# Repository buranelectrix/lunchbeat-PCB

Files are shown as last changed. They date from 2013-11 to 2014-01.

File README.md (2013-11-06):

lunchbeat - 1bit groovebox - PCB version
========================================
by Jan Cumpelik (jan@buranelectrix.com)

Hi. Here it is, Lunchbeat made it from breadboard to printed circuit board :)

"lunchbeat-PCB-firmware" contains source C code for Atmega328p 

"lunchbeat-PCB-hardware" contains resources for building Lunchbeat. Schematics, printed circuit board design. And whole Kicad project including library with used parts :)  Kicad is nice free software, use it :)

Feel free to use these files (read license first).

If you use this to create something cool, please let me know! 
If you find any flaw, please let me know!

Thank you, Jan.

The firmware is released under a GPL3.0 license.
The PCB layout and schematics are released under cc-by-sa 3.0 license. 

more info: www.buranelectrix.com

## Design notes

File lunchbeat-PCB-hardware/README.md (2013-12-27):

Lunchbeat hardware
==================

here you can find:

- whole KiCad project with latest Lunchbeat hardware revision

- partlist

- schematics

Part list now included in ODS file (OpenDocument Spreadsheet).

Jan

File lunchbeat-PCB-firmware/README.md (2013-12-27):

Lunchbeat version history file
==============================

Lunchbeat PCB 1.3
-----------------
* setup function renamed (for Arduino users)
+ SYNC IN now on ISP MISO pin
+ TRIG OUT goes always

Lunchbeat PCB 1.2
-----------------
+ selectable EXT or INT clock
+ clock division
+ setup mode

Lunchbeat PCB 1.1
-----------------
* several connections changed to better fit on PCB :)

Lunchbeat breadboard 1.0
------------------------
+ original Lunchbeat

======================
buranelectrix.com 2013
======================

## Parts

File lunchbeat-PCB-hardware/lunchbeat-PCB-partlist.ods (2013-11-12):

LUNCHBEAT PART LIST |  |  | buranelectrix.com
lunchbeat part | pcs | part name | manufacturer
mcu | 1 | ATMEGA328P-PU | ATMEL
mcu socket | 1 | ICVT-28P-W | NINIGI
crystal 16MHz | 1 | 16.00M-HC49-S | YIC
22pF capacitor | 2 | C315C220J2G5TA | KEMET
74595 shift register | 1 | 74HC595 | ST MICROELECTRONICS
shift register socket | 1 | ICVT-16P | NINIGI
red LED | 2 | 3mm LED | LUCKY LIGHT
blue LED | 8 | 3mm LED | LUCKY LIGHT
led resistors – depends on your LEDs | 10 | 1/4W3.3K | ROYAL OHM
pots | 6 | RK09K1130A8G | ALPS
buttons | 6 | TACT-65N-F | NINIGI
reset button | 1 | TACT-65R-F | NINIGI
reset resistor | 1 | 1/4W10K | ROYAL OHM
r2r resistors | 8 | 1/4W100K | ROYAL OHM
opamp | 1 | LM358AN | ST MICROELECTRONICS
opamp socket | 1 | ICVT-8P | NINIGI
output cap | 1 | KM10/63 | SAMXON
output protection r | 1 | 1/4W100R | ROYAL OHM
jack connector | 2 | FC68131 | CLIFF
battery holder | 1 | KEYS1295 | KEYSTONE
power switch | 1 | ZL201-10G | CONNFLY
5v stabiliser | 1 | L78L05ABZ | ST MICROELECTRONICS
330nF cap | 1 | C320C334K1R5TA | KEMET
220uF cap | 1 | KM220/25 | SAMXON
100nF coupling caps | 4 | C320C104K5R5TA | KEMET
ISP | 1 | DS1021-1*10SF11 | CONNFLY

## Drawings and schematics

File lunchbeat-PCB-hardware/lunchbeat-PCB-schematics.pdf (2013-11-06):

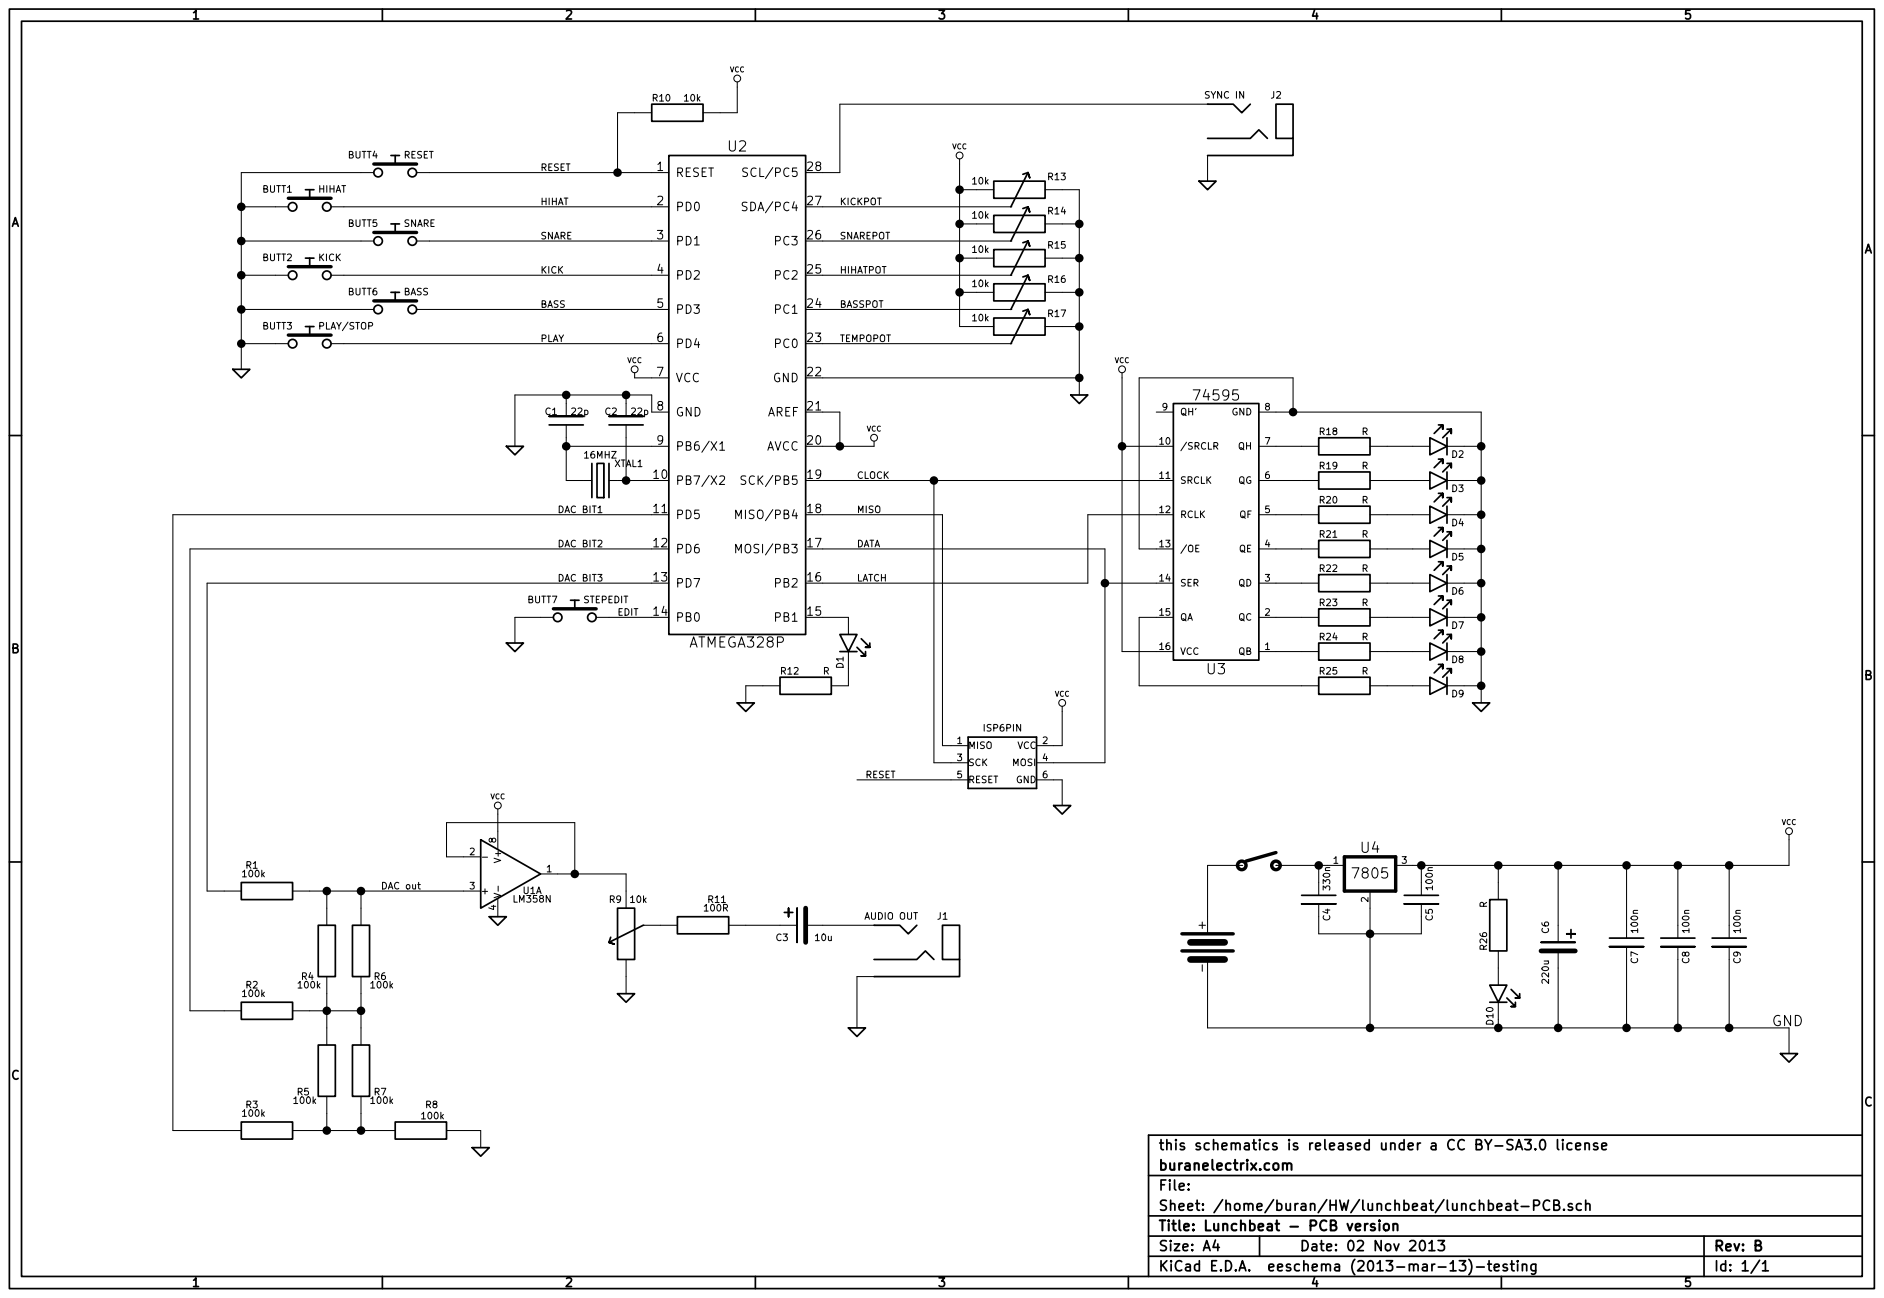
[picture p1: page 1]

DATA RESET HIHAT SNARE

TEMPOPOT BASSPOT HIHATPOT SNAREPOT KICKPOT

- +C6 220uC7 100n C8 100n D10 R26 R MISO 1 VCC 2 SCK 3 MOSI 4 RESET 5 GND 6

this schematics is released under a CC BY-SA3.0 license buranelectrix.com

Sheet: /home/buran/HW/lunchbeat/lunchbeat-PCB.sch File: Title: Lunchbeat - PCB version

KiCad E.D.A. eeschema (2013-mar-13)-testing Date: 02 Nov 2013

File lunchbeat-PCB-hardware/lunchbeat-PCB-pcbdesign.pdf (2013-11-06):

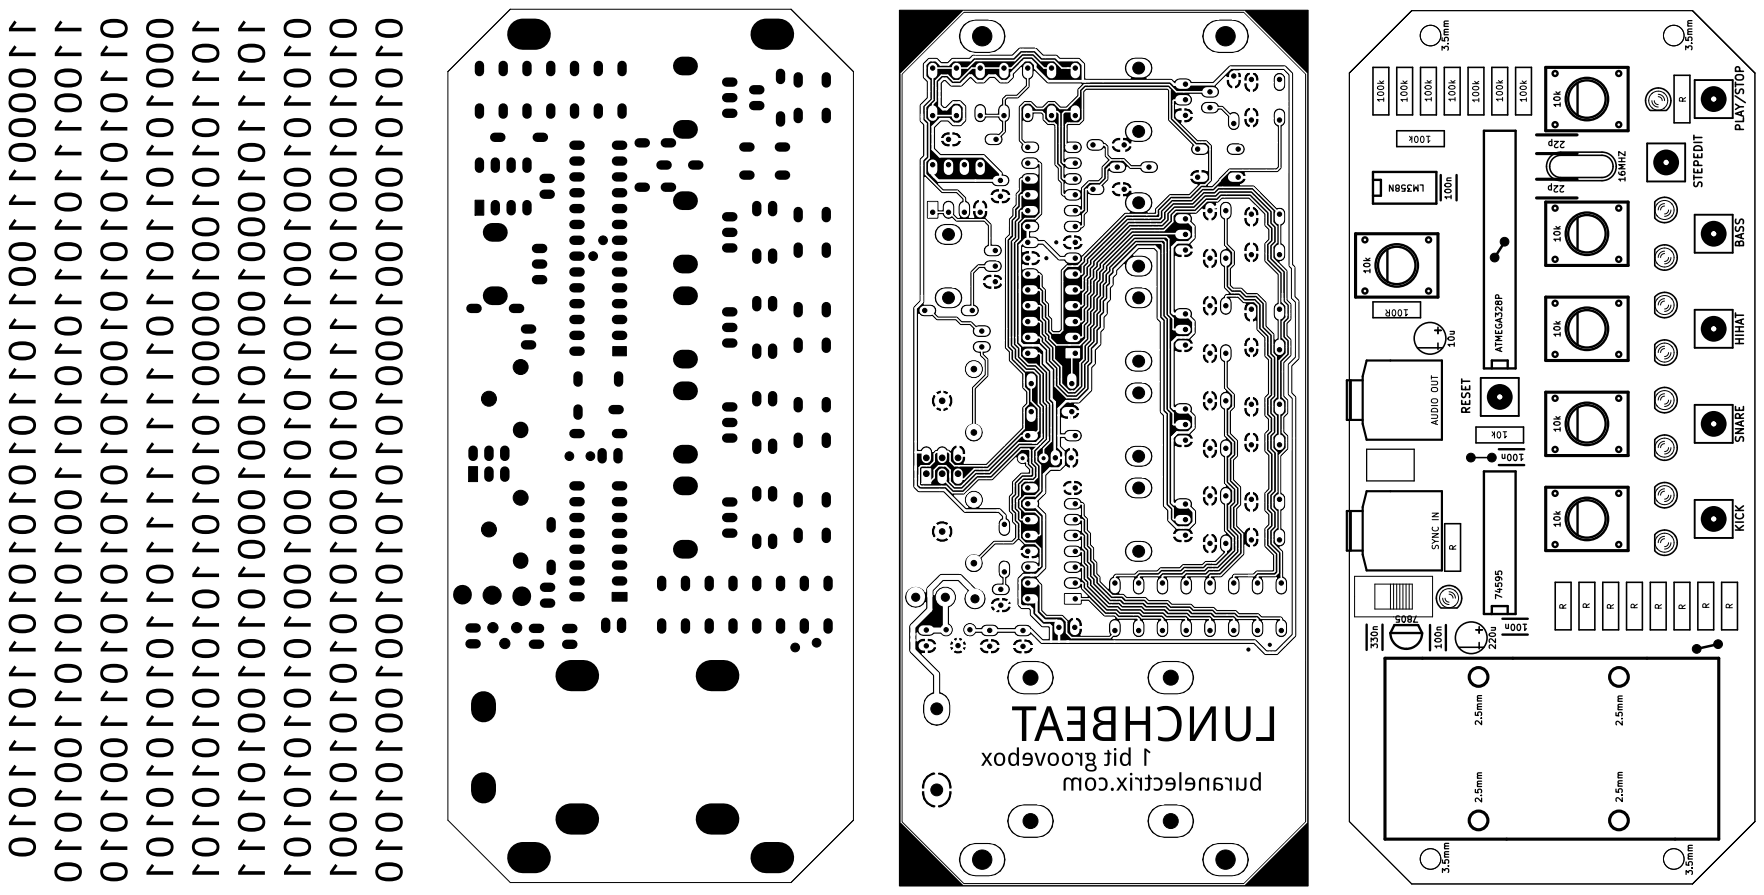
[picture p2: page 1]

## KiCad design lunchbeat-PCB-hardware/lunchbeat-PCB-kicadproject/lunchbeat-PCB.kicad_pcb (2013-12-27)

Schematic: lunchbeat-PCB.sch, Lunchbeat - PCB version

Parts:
6PIN1: ISP6PIN
B1: BATTERY
BUTT1: HIHAT
BUTT2: KICK
BUTT3: PLAY/STOP
BUTT4: RESET
BUTT5: SNARE
BUTT6: BASS
BUTT7: STEPEDIT
C1, C2: 22p
C3: 10u
C4: 330n
C5, C7, C8, C9: 100n
C6: 220u
D1, D2, D3, D4, D5, D6, D7, D8, D9, D10: LED
J1: AUDIO OUT
J2: SYNC IN
R1, R2, R3, R4, R5, R6, R7, R8: 100k
R9, R10, R13, R14, R15, R16, R17: 10k
R11: 100R
R12, R18, R19, R20, R21, R22, R23, R24, R25, R26: R
SW1: SW-PW
U1: LM358N
U2: ATMEGA328P
U3: 74595
U4: 7805
XTAL1: 16MHZ

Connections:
/BASS: BUTT6.2, U2.5 (PD3)
/BASSPOT: R16.2, U2.24 (PC1)
/CLOCK: 6PIN1.3 (SCK), U2.19 (SCK/PB5), U3.11 (SRCLK)
/DAC BIT1: R3.2, U2.11 (PD5)
/DAC BIT2: R2.2, U2.12 (PD6)
/DAC BIT3: R1.2, U2.13 (PD7)
/DAC out: R1.1, R4.2, R6.2, U1.3 (+)
/DATA: 6PIN1.4 (MOSI), U2.17 (MOSI/PB3), U3.14 (SER)
/EDIT: BUTT7.2, U2.14 (PB0)
/HIHAT: BUTT1.2, U2.2 (PD0)
/HIHATPOT: R15.2, U2.25 (PC2)
/KICK: BUTT2.2, U2.4 (PD2)
/KICKPOT: R13.2, U2.27 (SDA/PC4)
/LATCH: U2.16 (PB2), U3.12 (RCLK)
/MISO: 6PIN1.1 (MISO), U2.18 (MISO/PB4)
/PLAY: BUTT3.2, U2.6 (PD4)
/RESET: 6PIN1.5 (RESET), BUTT4.2, R10.1, U2.1 (RESET)
/SNARE: BUTT5.2, U2.3 (PD1)
/SNAREPOT: R14.2, U2.26 (PC3)
/TEMPOPOT: R17.2, U2.23 (PC0)
/batvcc: B1.2 (+), SW1.1
unnamed: D10.1, R26.1
unnamed: R9.3, U1.1, U1.2 (-)
unnamed: R9.2, R11.1
unnamed: C3.1, R11.2
unnamed: C4.2, SW1.2, U4.1 (IN)
unnamed: D1.2, R12.2
unnamed: D1.1, U2.15 (PB1)
unnamed: C2.2, U2.10 (PB7/X2), XTAL1.1
unnamed: J2.1, U2.28 (SCL/PC5)
unnamed: R2.1, R4.1, R5.2, R6.1, R7.2
unnamed: C1.2, U2.9 (PB6/X1), XTAL1.2
unnamed: C3.2, J1.1
unnamed: D6.1, R22.2
unnamed: D5.1, R21.2
unnamed: D4.1, R20.2
unnamed: D3.1, R19.2
unnamed: D2.1, R18.2
unnamed: R18.1, U3.7 (QH)
unnamed: R19.1, U3.6 (QG)
unnamed: R20.1, U3.5 (QF)
unnamed: R21.1, U3.4 (QE)
unnamed: R22.1, U3.3 (QD)
unnamed: R25.1, U3.15 (QA)
unnamed: D9.1, R25.2
unnamed: R24.1, U3.1 (QB)
unnamed: D8.1, R24.2
unnamed: R23.1, U3.2 (QC)
unnamed: D7.1, R23.2
unnamed: R3.1, R5.1, R7.1, R8.1
VCC: 6PIN1.2 (VCC), C5.2, C6.1, C7.2, C8.2, C9.2, R10.2, R13.3, R14.3, R15.3, R16.3, R17.3, R26.2, U1.8 (V+), U2.7 (VCC), U2.20 (AVCC), U2.21 (AREF), U3.10 (/SRCLR), U3.16 (VCC), U4.3 (OUT)
~: 6PIN1.6 (GND), B1.1 (-), BUTT1.1, BUTT2.1, BUTT3.1, BUTT4.1, BUTT5.1, BUTT6.1, BUTT7.1, C1.1, C2.1, C4.1, C5.1, C6.2, C7.1, C8.1, C9.1, D2.2, D3.2, D4.2, D5.2, D6.2, D7.2, D8.2, D9.2, D10.2, J1.3, J2.3, R8.2, R9.1, R12.1, R13.1, R14.1, R15.1, R16.1, R17.1, U1.4 (V-), U2.8 (GND), U2.22 (GND), U3.8 (GND), U3.13 (/OE), U4.2 (GND)

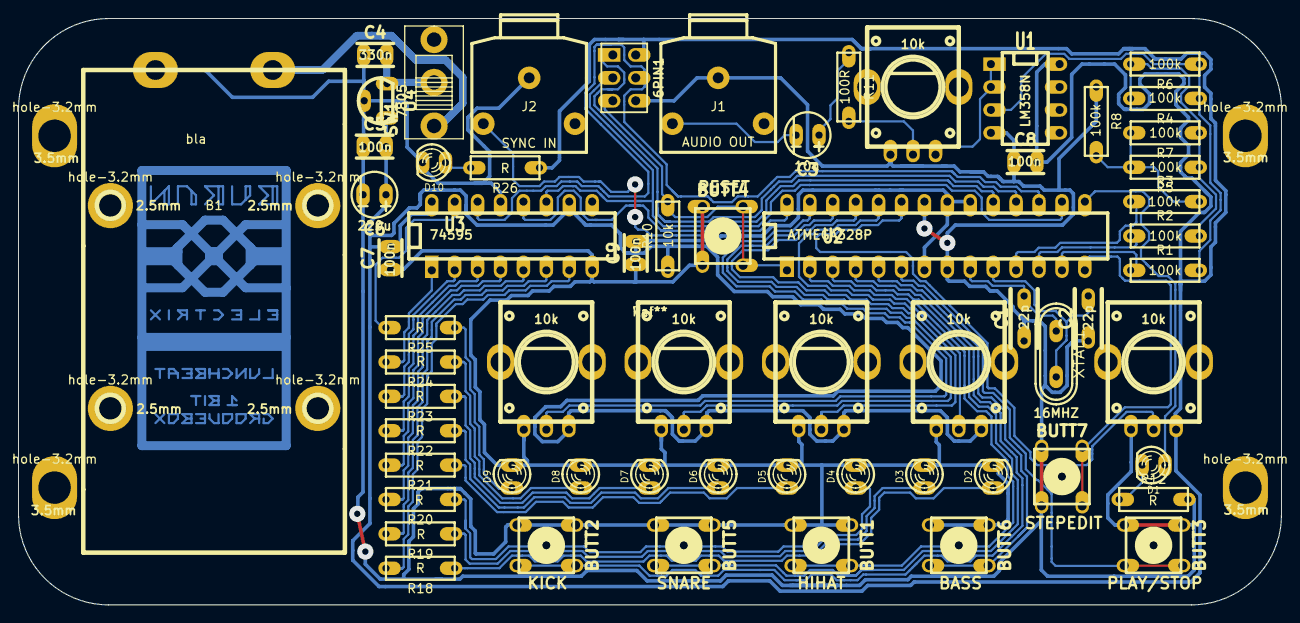
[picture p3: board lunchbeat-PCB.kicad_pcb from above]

Board: 2 copper layers, 140.0 x 65.0 mm, 72 parts (0 on the bottom side), 52 nets.

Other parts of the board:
Ref**: bla; buran-lunch-17x32-med
Ref**#2: Val**; lunchdeska1-l20
hole-3.2mm, hole-3.2mm#2, hole-3.2mm#3, hole-3.2mm#4: 2.5mm; hole-oval-3.2mm
hole-3.2mm#5, hole-3.2mm#6, hole-3.2mm#7, hole-3.2mm#8: 3.5mm; hole-oval-3.2mm

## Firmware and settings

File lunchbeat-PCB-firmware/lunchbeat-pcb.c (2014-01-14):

/*
 * =============================
 *   B U R A N E L E C T R I X 
 * =============================
 *
 *       L U N C H B E A T
 *
 *             P C B
 *
 *        1-bit groovebox 
 *
 * =============================
 *         version: 1.31
 *   target: atmega328p@16MHz
 *     (arduino compatible)
 * =============================
 *     (c) 2013 Jan Cumpelik
 * =============================
 *
 */

#include <avr/io.h>

#define F_CPU 16000000L
#include <util/delay.h>

#include <avr/interrupt.h>

#include "iolunch.h"


#define NOW 	0
#define PREV 	1
#define PLAY 	4
#define EDIT 	5
uint8_t rawbutton = 0; 
uint8_t button[2][6] = {{0,0,0,0,0,0},{0,0,0,0,0,0}} ; 	
uint8_t seq[8] = {	0b00000001,
			0b00000000,
			0b00000000,
			0b00000000,
			0b00000000,
			0b00000000,
			0b00000000,
			0b00000000 };
uint8_t playing = 0;
uint8_t extsyncmode = 0;
//uint8_t trigged = 0;
uint8_t editmode = 0;
volatile uint8_t playstep = 0;
volatile uint8_t newstep = 0;
volatile uint8_t editstep = 0;
volatile uint16_t tempo = 4000;
volatile uint16_t counter = 0;
volatile uint8_t setmode = 0;
uint8_t ledbar = 0;
uint8_t ledbarhlf = 0;
uint16_t pot[5];

#define KICKPOT		4
#define SNAREPOT	3
#define HATPOT		2
#define WAVEPOT		1
#define TEMPOPOT	0

#define KICK 	0
#define SNARE 	1
#define HAT 	2
#define WAVE	3
#define TEMPO	4

uint16_t gate[4];  
uint8_t division = 1;
uint8_t subdiv = 1;

#define TEMPOLED_OFF PORTB &= ~(1 << PB1)
#define TEMPOLED_ON  PORTB |= (1 << PB1)
		

/////////////////////////////////////////////////
//
// controls()
//
// cteni tlacitek a potenciometru
// reading buttons and potentiometers
//
/////////////////////////////////////////////////

void controls() {

// cteni hodnot z potenciometru
// reading potentiometers
	static uint8_t p = 0;
	pot[p] = readpot10b((p));
	p ++;
	if (p > 4) p = 0;

	static uint8_t debcycler = 0;
	debcycler ++;
	if (debcycler & 0x01) {
	
		// snimani buttonu do registru "rawbutton"
		// capture buttons to "rawbutton" variable
		uint8_t rawbutton = ~(PIND) & 0b00011111;

		// exchange kick and hat buttons - hardware issue
		if (~(PIND) & (1<<KICK)) {rawbutton |= (1<<HAT);} else {rawbutton &= ~(1<<HAT);}
		if (~(PIND) & (1<<HAT)) {rawbutton |= (1<<KICK);} else {rawbutton &= ~(1<<KICK);}

		if (~(PINB) & (1<<PB0)) rawbutton |= 0b00100000; // pridame edit tlacitko z portu B
								 // add EDIT button from B port

		// debouncing
		uint8_t but;
		for (but = 0; but < 6; but ++) {
				button[NOW][but] <<= 1;
			if (rawbutton & (1 << but)) {
				button[NOW][but] |= 0x01;
			} else {
				button[NOW][but] &= ~(0x01);
			}
		}
	}
	

	// akce pro prave stisknuta tlacitka 
	// button sound just pressed
	uint8_t tlac = 0;
	for (tlac = 0; tlac < 6; tlac++) {
		if (tlac < 4) {
			if ((button[NOW][tlac] == 0xff) && (button[PREV][tlac] != 0xff)) {

				if (setmode) {
					uint8_t divisioncheck = division;
					if (divisioncheck & (1 << (3 -tlac))) {
						divisioncheck &= ~(1 << (3 - tlac)) ;
					} 
					else {
						divisioncheck |= (1 << (3 - tlac));
					}
					if (divisioncheck >0) division = divisioncheck;
				}
				else if (editmode) {
					if (seq[editstep] & (1 << tlac)) {
						seq[editstep] &= ~(1 << tlac);
					}
					else {
						seq[editstep] |= (1 << tlac);
					}
				} 
				else {
					gate[tlac]	= 1;
				}
			}
		}
		
		// tlacitko play (tl. 4)
		// play button
		if (tlac == 4) {
			if ((button[NOW][PLAY] == 0xff) && (button[PREV][PLAY] != 0xff)) { 
				if (setmode) {
					if (extsyncmode) {
						extsyncmode = 0;
					//	DDRC |= (1 << PC5);
						PORTC &= ~(1 << PC5);
					}
					else {
						extsyncmode = 1;
					//	DDRC &= ~(1 << PC5);
						PORTC &= ~(1 << PC5);
					}
				}
				else if (playing) {
					playing = 0;
				} 
				else {
					if (extsyncmode) {
						playstep = 7;
						subdiv = 1;
					}
					else {
						playstep = 0;
						newstep = 1;
						subdiv = division;
						PORTC |= (1 << PC5);
						tempo = 5500 - (pot[TEMPOPOT] << 2);
					}	
					playing = 1;
					counter = 0;
				}
			}
		}
		
		// tlacitko edit (tl.5)
		// edit button
		if (tlac == 5) {
			if ((button[NOW][EDIT] == 0xff) && (button[PREV][EDIT] != 0xff)) {
				if (editmode) {
					editstep ++;
					if (editstep > 7) {
						editmode = 0;
						editstep = 0;
						ledbarhlf = 0;
					}
				} 
				else {
					editmode = 1;
				}
			}
		}

		button[PREV][tlac] = button[NOW][tlac];
	}
}



/////////////////////////////////////////////////
//
// lights()
//
/////////////////////////////////////////////////

void lights() {

	if (setmode) {
		ledbar = ((division) << 4);
		if (extsyncmode) ledbar |= 0b00000001;
		ledbarhlf = 0;
	}
	else if (editmode) {
		if (seq[editstep] & (1 << KICK))  {ledbar |= 0b11000000;} else {ledbar &= ~(0b11000000);}
		if (seq[editstep] & (1 << SNARE)) {ledbar |= 0b00110000;} else {ledbar &= ~(0b00110000);}
		if (seq[editstep] & (1 << HAT))   {ledbar |= 0b00001100;} else {ledbar &= ~(0b00001100);}
		if (seq[editstep] & (1 << WAVE))  {ledbar |= 0b00000011;} else {ledbar &= ~(0b00000011);}

		ledbar 		|=  (1<<(7-editstep));
		ledbarhlf  	 = ~(1<<(7-editstep));
	}
	else {
		if (gate[KICK] ) {ledbar |= 0b11000000;} else {ledbar &= ~(0b11000000);}
		if (gate[SNARE]) {ledbar |= 0b00110000;} else {ledbar &= ~(0b00110000);}
		if (gate[HAT]  ) {ledbar |= 0b00001100;} else {ledbar &= ~(0b00001100);}
		if (gate[WAVE] ) {ledbar |= 0b00000011;} else {ledbar &= ~(0b00000011);}
	}
}



/////////////////////////////////////////////////
/////////////////////////////////////////////////
//
//   M A I N 
//
/////////////////////////////////////////////////
/////////////////////////////////////////////////


int main() {

	// do setup 
	setup_lunchbeat();

	// and go for infinite loop
	for (;;) {
		
		controls();		// read buttons and pots
		lights();		// compute which LED to light up
		
		if (newstep) {
			newstep = 0;
			uint8_t i;
			for (i = 0; i < 4; i++) {
				if (seq[playstep] & (1 << i)) gate[i] = 1;			
			}
		}
	}
}



/////////////////////////////////////////////////
/////////////////////////////////////////////////
//
//   I N T E R R U P T 
//
/////////////////////////////////////////////////
/////////////////////////////////////////////////


ISR(TIMER1_COMPA_vect) {


	// counter pocita tempo 
	// counter variable counts tempo
	if (playing) {
		counter ++;
		
		uint8_t trigpin = 0;
		static uint8_t lasttrigpin = 0;

		if (extsyncmode) { // externi clock
	
			// zmena na trig in na MISO pinu
			//if (PINC & (1 << PC5)) {trigpin = 1;} else {trigpin = 0;}
			if (PINB & (1 << PB4)) {trigpin = 1;} else {trigpin = 0;}

			// novy krok 
			// new step
			if ((trigpin == 1) && (lasttrigpin == 0)) {
				subdiv --;
				if (subdiv == 0) {
					subdiv = division ;
					counter = 0;
					newstep = 1;
					playstep ++;
					if (playstep > 7) playstep = 0;
					PORTC |= (1 << PC5); //trigout on
				}
			}
			
			lasttrigpin = trigpin;
		}  
		else {  // interni clock
			
			// novy krok
			// new step
			if (counter > tempo)   {
				tempo = 5500 - (pot[TEMPOPOT] << 2);
				counter = 0;
				newstep = 1;
				playstep ++;
				if (playstep > 7) playstep = 0;

				subdiv --;
				if (subdiv == 0) {
					subdiv = division ;
					PORTC |= (1 << PC5); // trigout on
				}
			}
		}
		
		// trig out off
		if (counter > 0x8f) {  // cca 10ms
			PORTC &= ~(1 << PC5);
		}

	}
	

	///////////////////////
	// vypocet zvuku
	// sound modelling :)

	// kick
	static uint8_t kick = 0;
	static uint16_t kickfreq = 2;
	if (gate[KICK]) {
		if (gate[KICK] == 1) { // zvuk zrovna zacal - sound starts
			kickfreq = 2;
		}
		gate[KICK] ++;
		if (gate[KICK] > ((pot[KICKPOT] << 3) + 0x01ff)) { // cas pro konec zvuku - sound ends
			gate[KICK] = 0;  // ticho
			kick = 0;
		} 
		else { // zvuk hraje - sound plays
			if (gate[KICK] == kickfreq) {
				if (kick) {
					kick = 0;
				} else {
					kick = 1;
				}
				kickfreq += (kickfreq>>4) + (64-(pot[KICKPOT]>>4));
			}
		}
	}

	//snare 
	static uint8_t snare = 0;
	static uint16_t snarefreq = 2;
	static uint16_t snarelfsr = 0b0011010010100100; // seed pro linear feedback shift register
	if (gate[SNARE]) {
		if (gate[SNARE] == 1) {
			snarefreq = 2;
		}
		gate[SNARE] ++;
		if (gate[SNARE] > ((pot[SNAREPOT]<<2) + 0x01ff)) { // cas pro konec zvuku - end of sound
			gate[SNARE] = 0;  // ticho - silence
			snare = 0;
		} else { 			// zvuk hraje - sound is playing
		// prvni cast zvuku - first part of sound
			if (gate[SNARE] < (pot[SNAREPOT] + 0x0090)) {

				if ((gate[SNARE] & 128) ||	 (!(gate[SNARE] % ((pot[SNAREPOT] >> 5) + 3)))) {
					if ( ((snarelfsr & 3) == 0) || ((snarelfsr & 3) == 3) ) {
						if (snare) {snare = 0;} else {snare = 1;}
						snarelfsr >>= 1;
						snarelfsr |= 0b1000000000000000;
					} else {
						snarelfsr >>= 1;
					}
				}
			}
			else 
			// druha cast zvuku - second part of sound
			{
				if ((gate[SNARE] & 32) ||	 (!(gate[SNARE] % ((pot[SNAREPOT] >> 4) + 5)))) {
					if ( ((snarelfsr & 3) == 0) || ((snarelfsr & 3) == 3) ) {
						if (snare) {snare = 0;} else {snare = 1;}
						snarelfsr >>= 1;
						snarelfsr |= 0b1000000000000000;
					} else {
						snarelfsr >>= 1;
					}
				}
			}
		}
	}

	//hat 
	uint8_t hat = 0;
	static uint16_t hatlfsr = 0b0100101010001010; // seed for linear feedback shift register
	if (gate[HAT]) {
		gate[HAT] ++;
		if (gate[HAT] > (pot[HATPOT] + (pot[HATPOT] >> 2) + 0x01ff)) { // cas pro konec zvuku - sound ends here
			gate[HAT] = 0;  // ticho - silence
			hat = 0;
		} else { // zvuk hraje - sound is playing
			if (!(gate[HAT] % (((pot[HATPOT] + 190) >> 6) ))) {
				if ( ((hatlfsr & 3) == 0) || ((hatlfsr & 3) == 3) ) {
					hat = 1;
					hatlfsr >>= 1;
					hatlfsr |= 0b1000000000000000;
				} else {
					hatlfsr >>= 1;
				}
			}
		}
	}
	
	//wave 
	static uint8_t wave = 0;
	static uint16_t wavefreq = 1;

	if (button[NOW][WAVE] == 0x00) {
		if (!(playing   &&    ((seq[playstep] & (1 << WAVE))))) {
			gate[WAVE] = 0;
		}
	}
	if (gate[WAVE]) {
		gate[WAVE] ++;
		if (!(gate[WAVE] % wavefreq )) {
			wavefreq = 50 + (255 - (pot[WAVEPOT] >> 2));
			gate[WAVE] = 1;
			if (wave) {wave = 0;} else {wave = 1;}
		}
	} 
	else {
		if ((!playing) || (!(seq[playstep] & (1 << WAVE)))) {
			wave = 0;
		}
	}



	// smichani vsech zvuku dohromady
	// add all sounds together
	uint8_t mix = kick + snare + hat + wave;	

	// zde uz primo vystup na prevodnik
	// prevodnik je na 5, 6 a 7 pinu portu D
	//
	// output to DAC
	// DAC is on PD5, PD6 and PD7 pins
	uint8_t portmp = (mix << 5);
	portmp |= 0b00011111;	// pullups on PD0 - PD4
	PORTD = portmp;




	//////////////////////////////////////////////////////
	// out lights
	/////////////////////////////////////////////////////
	uint8_t leds = ledbar;
	static uint8_t darkcycle = 0;
	darkcycle ++;
	if (darkcycle > 25) darkcycle = 0;
	if (darkcycle) leds &= ~(ledbarhlf);
	ledbarout(leds);

	//  tempo LED
	if (setmode) {
		static uint16_t setled = 0;
		setled ++;
		if (setled > 500) {
			setled = 0;
			if (PORTB & (1 << PB1)) {
				TEMPOLED_OFF;
			} 
			else {
				TEMPOLED_ON;
			}
		}
	}

	else {
		if (playing) {
			if (extsyncmode) {
				if (PINB & (1 << PB4)) {
					TEMPOLED_ON;
				} 
				else {
					if (darkcycle) {
						TEMPOLED_OFF;
					}
					else {
						TEMPOLED_ON;
					}
				}
			}
			else
			{
				if (counter < (tempo >> 3)) {TEMPOLED_ON;} else {TEMPOLED_OFF;}
			}
		}
		else {
			if (extsyncmode) {
				if (PINC & (1 << PC5)) {
					if (darkcycle) {
						TEMPOLED_OFF;
					}
					else {
						TEMPOLED_ON;
					}
				}
				else {
					TEMPOLED_OFF;
				}
			}
			else {
				TEMPOLED_OFF;
			}
		}
	}

	/////////////////////////////////////////////////////////
	// setup mode
	//
	static uint16_t setupcounter = 0;
	
	if (PINB & (1 << PB0)) {
		setupcounter = 0;
	} 
	else {
		setupcounter ++;
	}

	if (setupcounter == 0x7fff) {
		if (setmode) {
			setmode = 0;
			editstep = 0;
			editmode = 0;
		}
		else {
			setmode = 1;
		}
	}
}

/*
 * konec programu
 * end of sranda
 */

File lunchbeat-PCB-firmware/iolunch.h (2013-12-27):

/*
 * =============================
 *   B U R A N E L E C T R I X 
 * =============================
 *
 *       L U N C H B E A T
 *
 *        1-bit groovebox 
 *
 * =============================
 *           iolunch.h
 *       for Lunchbeat 1.3
 * setup routine
 * ADC (reading pot) routines
 * SPI out (for LEDs) routine
 * =============================
 *     (c) 2013 Jan Cumpelik
 * =============================
 *
 */


void setup_lunchbeat() {
	
	// tlacitko EDIT - EDIT button
	DDRB &= ~(1 << PB0); // input
	PORTB |= (1 << PB0); // pullup on

	// tempo LED
	DDRB |= (1 << PB1);
	PORTB &= ~(1 << PB1);

	// port D - D0-D4 vstup, D5-D7 vystup
	// port D - D0-D4 input, D5-D7 output
	DDRD  = 0b11100000;
	PORTD = 0b00011111; 
	
	// trigout
	DDRC |= (1 << PC5);
	PORTC &= ~(1 << PC5);


	// interni ADC nastaveni
	// internal ADC setup
	//ADCSRA |= (0 << ADPS2) | (0 << ADPS1) | (0 << ADPS0); //   5   us
	//ADCSRA |= (0 << ADPS2) | (1 << ADPS1) | (0 << ADPS0); //   6.5 us
	ADCSRA |= (0 << ADPS2) | (1 << ADPS1) | (1 << ADPS0); //  10   us
	//ADCSRA |= (1 << ADPS2) | (0 << ADPS1) | (0 << ADPS0); //  17   us
	//ADCSRA |= (1 << ADPS2) | (0 << ADPS1) | (1 << ADPS0); //  29.6 us
	//ADCSRA |= (1 << ADPS2) | (1 << ADPS1) | (0 << ADPS0); //  56   us
	//ADCSRA |= (1 << ADPS2) | (1 << ADPS1) | (1 << ADPS0); // 112   us
	ADMUX |= (1 << REFS0);
	//ADMUX |= (1 << ADLAR); // left adjust - pro 8-bit cteni pouze ADCH
	//ADMUX &= ~(1 << ADLAR);
	ADCSRA |= (1 << ADEN); // enable ADC

	//SPI pins
	DDRB |= (1 << PB3); // mosi - vystup - output
	DDRB &= ~(1 << PB4); // miso - vstup - input
	DDRB |= (1 << PB5); // sck - vystup  - output

	DDRB |= (1 << PB2); // led latch pin
	PORTB &= ~(1 << PB2); // set low
	
	// SPI nastaveni
	SPCR &= ~(1<<SPR0) & ~(1<<SPR1); // rychlost - speed
	SPCR &= ~(1<<SPI2X);             // rychlost - speed
	SPCR |= (1<<DORD);               // data order
	SPCR |=  (1<<SPE) | (1<<MSTR);	// spi enable, spi master
	
	// interrupt nastaveni
	cli();
	//TCCR1A  = (1 << COM1A0);		// toggle OC1A pin (PB1) on compare match
	TCCR1B  = (1 << WGM12); 		// CTC mode
	TCCR1B |= (1 << CS11);			// prescaler 8
	TIMSK1 |= (1 << OCIE1A);		// ctc interrupt enable
	OCR1A = 128;						// 15625Hz

	sei();
}

void ledbarout(uint8_t value) {

	SPDR = value;
	while(!(SPSR & (1<<SPIF)));
	PORTB |= (1 << PB2); // latch it
	PORTB &= ~(1 << PB2);
}
	
uint8_t readpot8b(uint8_t p) 
{
	// set multiplexer
	p &= 7;
	ADMUX &= ~(7);
	ADMUX |= p;
	ADMUX |= (1<<ADLAR); // left adjust 
	// start ADC conversion
	ADCSRA |= (1 << ADSC); // start single conversion
	while (ADCSRA & (1 << ADSC)) {} // wait for result
	// use left adjusted ADCH
	uint8_t pot = ADCH;
	return pot;
}

uint16_t readpot10b(uint8_t p) 
{
	// set multiplexer
	p &= 7;
	ADMUX &= ~(7);
	ADMUX |= p;
	ADMUX &= ~(1<<ADLAR); // no left adjust 
	// start ADC conversion
	ADCSRA |= (1 << ADSC); // start single conversion
	while (ADCSRA & (1 << ADSC)) {} // wait for result
	// convert to 16 bit variable
	uint8_t potL = ADCL;
	uint8_t potH = ADCH;
	uint16_t pot = potH;
	pot <<= 8;
	pot |= potL;
	return pot;
}

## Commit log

2013-10-28 original upload
    [lunchbeat-PCB.dsn, lunchbeat-PCB.kicad_pcb, lunchbeat-PCB.sch]
2013-11-12 part list release
    [lunchbeat-PCB-partlist.ods]
2014-01-14 trig out in division fix
    [lunchbeat-pcb.c]

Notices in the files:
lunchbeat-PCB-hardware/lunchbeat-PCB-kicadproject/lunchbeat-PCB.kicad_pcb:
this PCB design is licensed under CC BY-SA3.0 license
